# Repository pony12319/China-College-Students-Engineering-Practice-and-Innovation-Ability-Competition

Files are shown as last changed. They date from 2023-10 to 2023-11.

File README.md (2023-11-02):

# China-College-Students-Engineering-Practice-and-Innovation-Ability-Competition
2023年工训赛垃圾分类赛道代码汇总（传送带方案）
使用传送带方案，当投入多个垃圾时，第二个传送带速度更快，装有激光对射开关，可以把多个垃圾分离成一个垃圾倒入云台中
《初赛》、《决赛&国赛选拔赛》包含的是电控代码

大文件无法上传，已经整理好放百度网盘：
链接：https://pan.baidu.com/s/1K9raEiHcVAuprJ7IywbOOw?pwd=yjwt 
提取码：yjwt（包含文件：机械设计代码、两个数据集、改过的yolov5、2022年老代码）

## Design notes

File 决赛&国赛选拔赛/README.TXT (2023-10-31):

实验器材:
	正点原子精英STM32F103开发板
说明：
	1、决赛时不再满载检测，创新环节也不需要加入称重功能
	2、启用激光后对射开关速度会很慢
	3、使用光电开关跳过动画，一定要把握好时间，不然js无法正常工作（建议自己看看会出现什么结果，这次选拔赛就寄在这里...）
	4、标*是需要接线的
	
使用的引脚:
	1、VL53L0X：
		SDA--------------->PF1*
		SCL--------------->PF0*
		XSHUT1（有害）  ------------->PF2*
		XSHUT2（可回收）   ------------->PF3*
		XSHUT3（厨余）   ------------->PF4*
		XSHUT4（其他）   ------------->PF5*
		
	2、LED:
		LED0-------------->PB5
		LED1-------------->PE5
	3、KEY：
		KEY0-------------->PE4
		KEY1-------------->PE3
		WK_UP------------->PA0
	4、TPAD：
		TPAD--------------->PA0 TIM5CH2
	5、LCD:
		PB0
		PD0 PD1 PD4 PD5 PD8 PD9 PD10 PD14 PD15
		PE7 PE8 PE9 PE10 PE11 PE12 PE13 PE14 PE15
		PG0 PG12
	6、SPI：
		PB13 PB14 PB15
	7、W25QXX：
		PB12
	8、SDIO_SDCARD:
		PC8 PC9 PC10 PC11 PC12
		PD2 PD7
	9、控制倾倒的舵机：
		竖直舵机----------->PB6 TIM4CH1*
		水平舵机----------->PB9 TIM4CH4*
	10、压缩机构（24v）
		CW---------------->PF14*
		CCW--------------->PF15*
	11、控制开合的舵机：
		PB1 TIM3CH4*
	12、传送带电机：
		PWM1--------------->PA2 TIM5CH3*
		DIR1--------------->PG3*
		PWM2--------------->PA3 TIM5CH4*
		DIR1--------------->PG4*
	13、光电开关：
		SGN---------------->PF7*
	14、称重模块:
		SCK----------------->PG5*
		DOUT---------------->PG6*
	15、激光对射：
		SGN----------------->PG9*
	16、电机驱动器：
		电机1---------------->PA6 TIM3CH1*
		电机2---------------->PA7 TIM3CH2*

注意事项:
	1、js发送数据必须带上回车换行符
	2、A-------->有害垃圾
	   B-------->可回收垃圾
	   C-------->厨余垃圾
	   D-------->其他垃圾

-------------------------------------------------------------------------------------------

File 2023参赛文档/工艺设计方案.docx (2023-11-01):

四川省大学生工程训练综合能力竞赛 | 工艺设计方案 The Process Plan | | 编 号

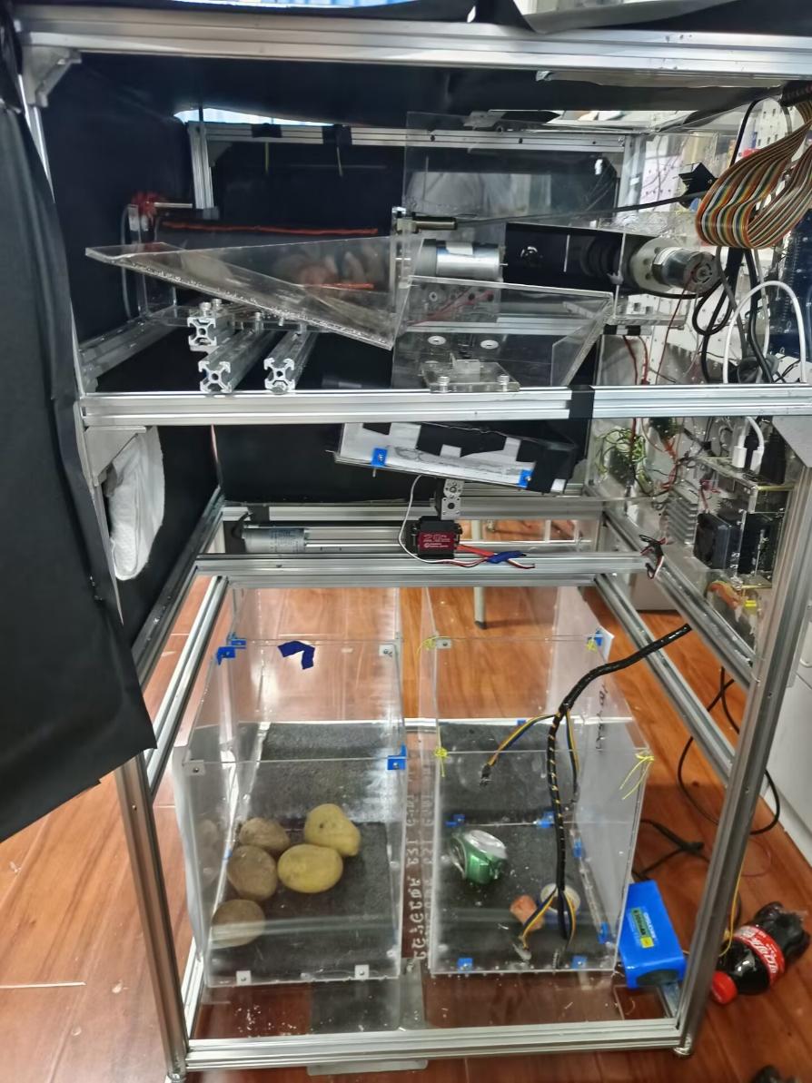
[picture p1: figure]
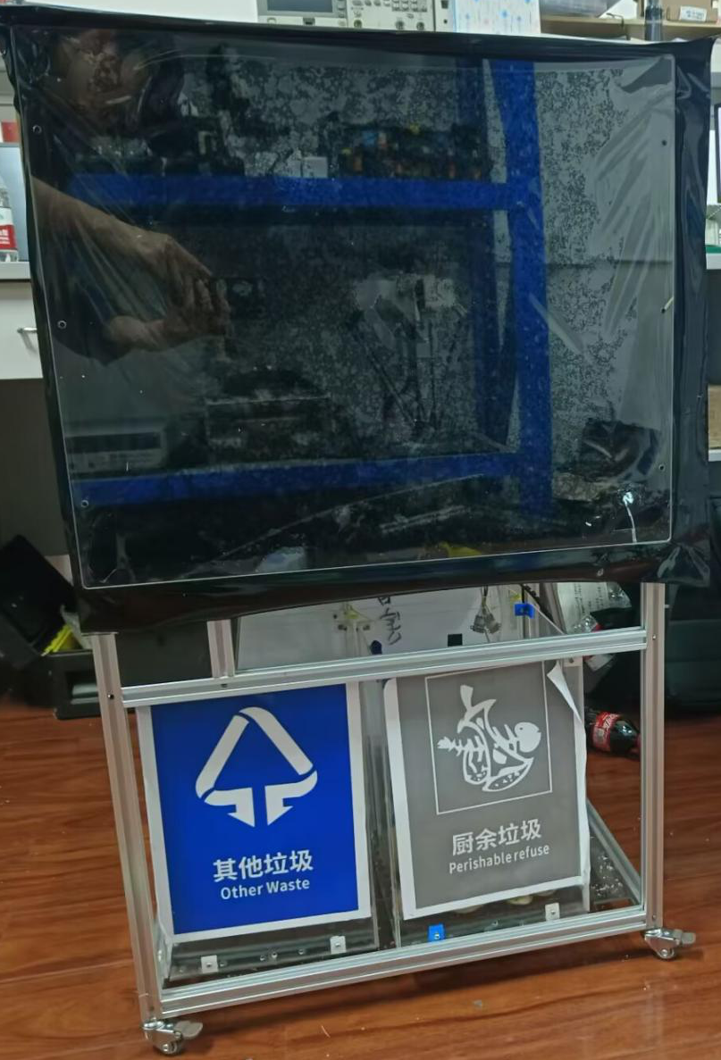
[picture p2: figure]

第一幅照片（作品正面） （注意照片的放置方向与页面方向一致， 照片上不允许出现参赛学校信息，阅后删除。） | | 第二幅照片（作品侧面） （注意照片的放置方向与页面方向一致， 照片上不允许出现参赛学校信息，阅后删除。）

学校名称：西南石油大学 参赛项目：生活垃圾智能分类

装

订

线

四川省大学生工程训练综合能力竞赛 | | | | | | | 机械加工工艺过程卡片 Machining Process Card | | | | | | 共 页 | | 第2页 | 编 号
| | | | | | | | | | | | | 产品名称 | | 垃圾桶 | 生产纲领 | 5000件/年
| | | | | | | | | | | | | 零件名称 | | 亚克力一体件 | 生产批量 | 420件/月
材料 | 亚克力 | 毛坯种类 | 亚克力料板 | | 毛坯外形尺寸 | | | 1200*900 | | 每毛坯可制作件数 | | 1 | 每台件数 | | | 备注
序 号 | 工序 名称 | 工序内容 | | | | | | | 工 序 简 图 | | | | 机床 夹具 | | 刀具 | 量具 辅具 | 工时 （min）
1 | 切割 | 激光切割 | | | | | | | 下料-对刀-切割-取件 | | | | 低压吸盘 | | CO2激光 | 刀补0.2mm | 2min
2 | 切割 | 激光切割 | | | | | | | 下料-对刀-切割-取件 | | | | 低压吸盘 | | CO2激光 | 刀补0.2mm | 4min
3 | 切割 | 激光切割 | | | | | | | 下料-对刀-切割-取件 | | | | 低压吸盘 | | CO2激光 | 刀补0.2mm | 30s
4 | 切割 | 激光切割 | | | | | | | 下料-对刀-切割-取件 | | | | 低压吸盘 | | CO2激光 | 刀补0.2mm | 5min
5 | 切割 | 亚克力热弯 | | | | | | | 放置-加热-弯折-冷却-退火 | | | | T型螺栓 | | 电热丝 | 角度尺 | 2min
6 | 切割 | 亚克力热弯 | | | | | | | 放置-加热-弯折-冷却-退火 | | | | T型螺栓 | | 电热丝 | 角度尺 | 4min
7 | 切割 | 亚克力热弯 | | | | | | | 放置-加热-弯折-冷却-退火 | | | | T型螺栓 | | 电热丝 | 角度尺 | 3min
| | | | | | | | | | | | | | | 编制（日期） | 审核（日期） | 标准化（日期）
标记 | 处数 | 更改文件号 | | 签字 | | 日期 | | | | | | | | | | 会签（日期）

学校名称：西南石油大学 参赛项目：生活垃圾智能分类

装

订

线

四川省大学生工程训练综合能力竞赛 | 加工工艺分析 Processing Technology Analysis | 共 页 | 第3页 | 编 号
| | 产品名称 | 垃圾桶 | 生产纲领 | 5000件/年
| | 零件名称 | | 生产批量 | 420件/月

1. 切割：这是亚克力一体件制作的初始步骤，也是最重要的一步。首先，需要根据设计图纸和产品要求，选择合适的亚克力板材。然后，使用专业的亚克力切割机进行切割。这个过程中，切割速度、深度和精度的控制都非常重要。如果切割过快或过深，可能会导致亚克力板材破裂；如果切割不平整，可能会影响后续的热弯和组装。

2. 热弯：热弯是将切割好的亚克力板材通过加热使其软化，然后通过压力使其弯曲成所需形状的过程。这个过程需要使用专业的热弯机，通过电热丝或者火焰加热亚克力板材，然后通过模具进行弯曲。热弯过程中，加热温度和时间的控制非常关键。如果温度过高或时间过长，可能会导致亚克力板材过热熔化；如果温度过低或时间过短，可能会导致亚克力板材弯曲不足。同时，弯曲力度和速度的控制也非常重要。如果力度过大或速度过快，可能会导致亚克力板材破裂；如果力度过小或速度过慢，可能会导致亚克力板材弯曲过度。

3. 后处理：热弯完成后，亚克力一体件还需要经过打磨、抛光等后处理工序，以提高其表面光洁度和美观度。这个过程需要使用专业的打磨机和抛光机，通过不同的砂纸和抛光膏进行打磨和抛光。后处理过程中，需要注意控制打磨和抛光的力度和速度，以防止亚克力板材破损或者表面划伤。

4. 表面处理：最后，根据需要可能还需要进行喷漆、丝印等表面处理，以增加产品的耐用性和美观性。这个过程需要使用专业的喷漆机和丝印机，通过选择不同的颜色和图案进行喷漆和丝印。表面处理过程中，需要注意控制喷漆和丝印的厚度和均匀度，以防止产品表面不平整或者颜色不均匀。

学校名称：西南石油大学 参赛项目：生活垃圾智能分类

装

订

线

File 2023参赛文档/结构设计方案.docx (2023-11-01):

四川省大学生工程训练综合能力竞赛项目
结构设计方案 | | | | 编 号

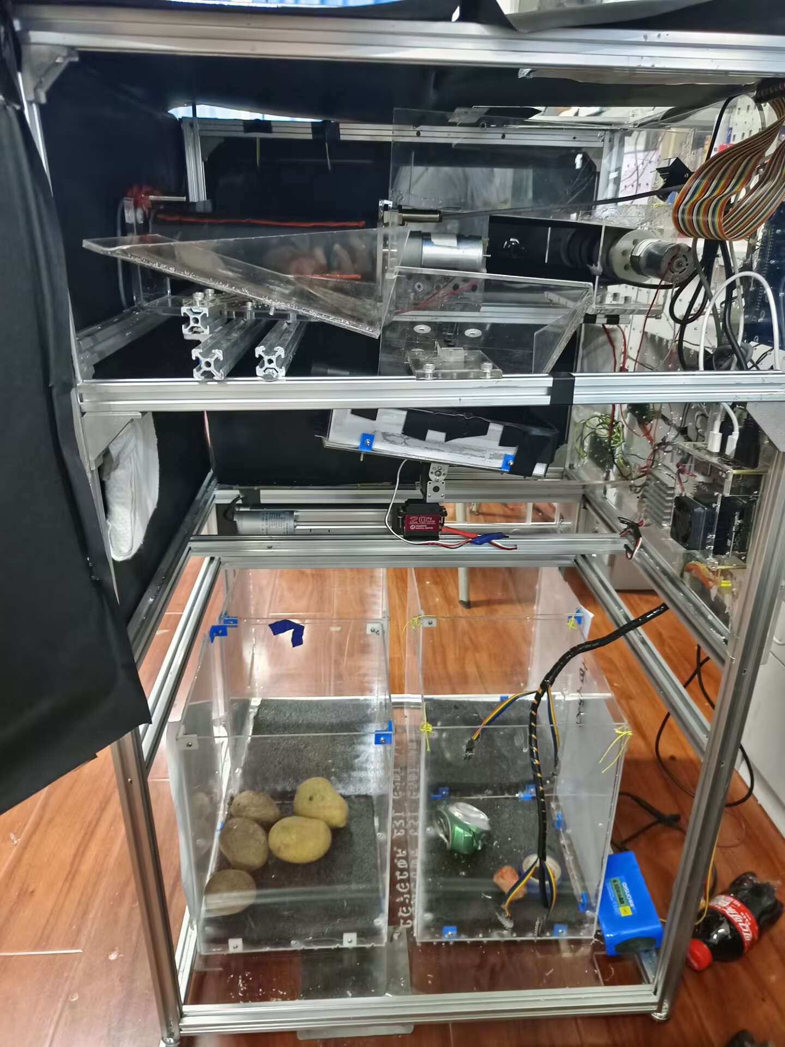
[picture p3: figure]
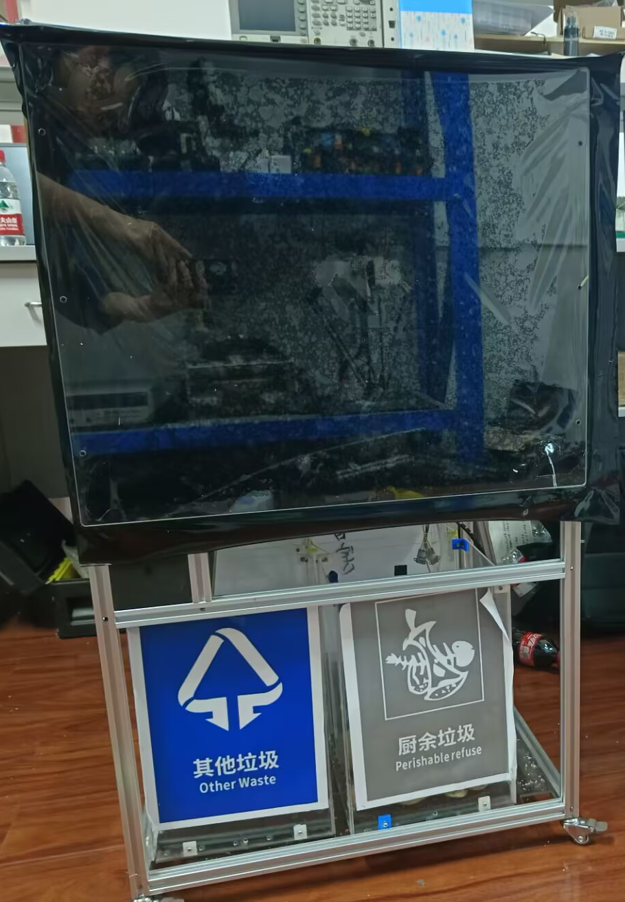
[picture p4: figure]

产品名称 | 垃圾桶 | 共 5 页 | 第 1 页 | | 编 号

学校名称：西南石油大学 队号 ：Z2-29 参赛项目：生活垃圾智能分类

装

订

线

四川省大学生工程训练综合能力竞赛项目
结构设计方案 Structure Design Scheme | | | | 参赛项目
| | | | 生活垃圾智能分类

1、设计思路

外壳采用3mm亚克力与黑磨砂纸的组合以提供利于视觉识别的环境；框架采用铝型材及圆头螺丝装配来保证整体框架的稳定性及应有的韧性、刚性等等；线路板部分采用5mm亚克力切割安装，保证了良好的可加工性与安装稳定性；内部异性结构件采用复合材料3D打印，使得材料的强度有保障；对于部分非标承重件采用了金属烧结，以获得优异的结构性能。

2、总体结构方案

先准备好各项材料，用铝型材组装出整体框架，安装底板，安装脚轮，安装云台，安装压缩装置，安装开合装置，安装线路板，安装传送带，安装滑道，安装四周板，安装顶板。

3、总结和体会

1、再一次考验并验证了我的制造加工装配能力；

2、为结构工业化提出并实践了部分参考；

3、对身体素质进行了一些简单的测试；

4、再次验证了我的个人效率及积极性。
产品名称 | 垃圾桶 | 共 5 页 | 第 2 页 | | 编 号

学校名称：西南石油大学 队号 ：Z2-29 参赛项目：生活垃圾智能分类

装

订

线

四川省大学生工程训练综合能力竞赛项目
结构设计方案 Structure Design Scheme | | | | 参赛项目
| | | | 生活垃圾智能分类

4、 结构设计创新特色说明

1、对部分结构件采用了一体化成型；

2、采用了工业级的激光对射开关并修改至能被单片机使用；

3、对铝型材采用了空间利用率更高的连接方式；

4、充分使用铝型材专用配件使得垃圾箱整体更符合日常使用习惯并获得更大的灵活性。
产品名称 | 垃圾桶 | 共 5 页 | 第 3 页 | | 编 号

学校名称：西南石油大学 队号 ：Z2-29 参赛项目：生活垃圾智能分类

装

订

线

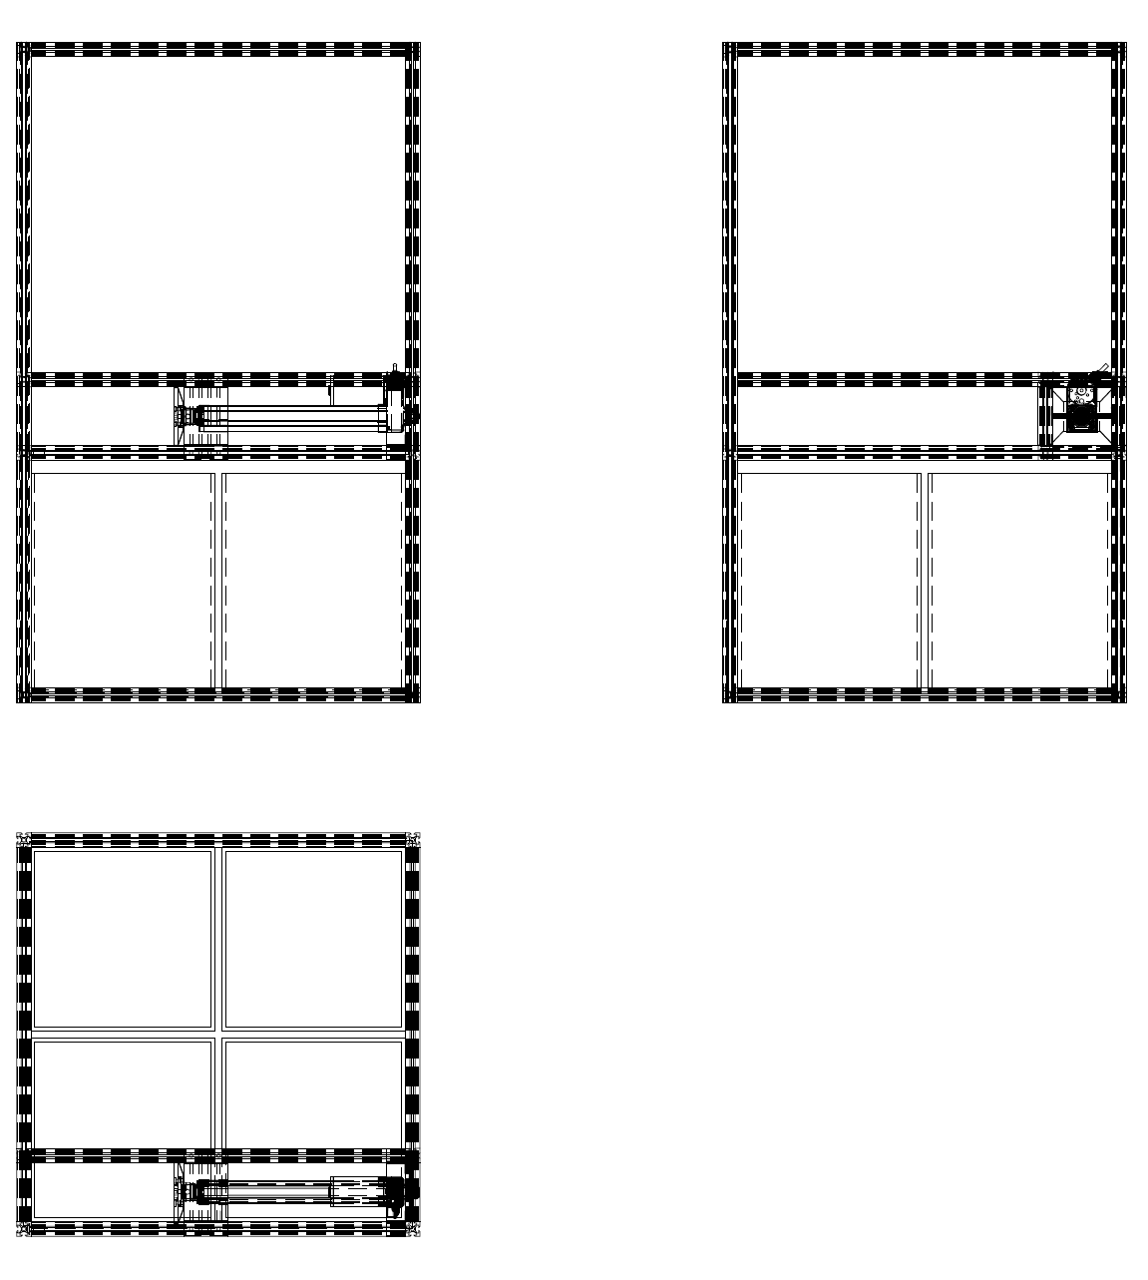
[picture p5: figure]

| 装配图 | 比例 | 第 4 页
| 四川省大学生工程训练综合能力竞赛项目 | 1：20 | 共 5 页

装

订

线

学校名称：西南石油大学 队号 ：Z2-29 参赛项目：生活垃圾智能分类

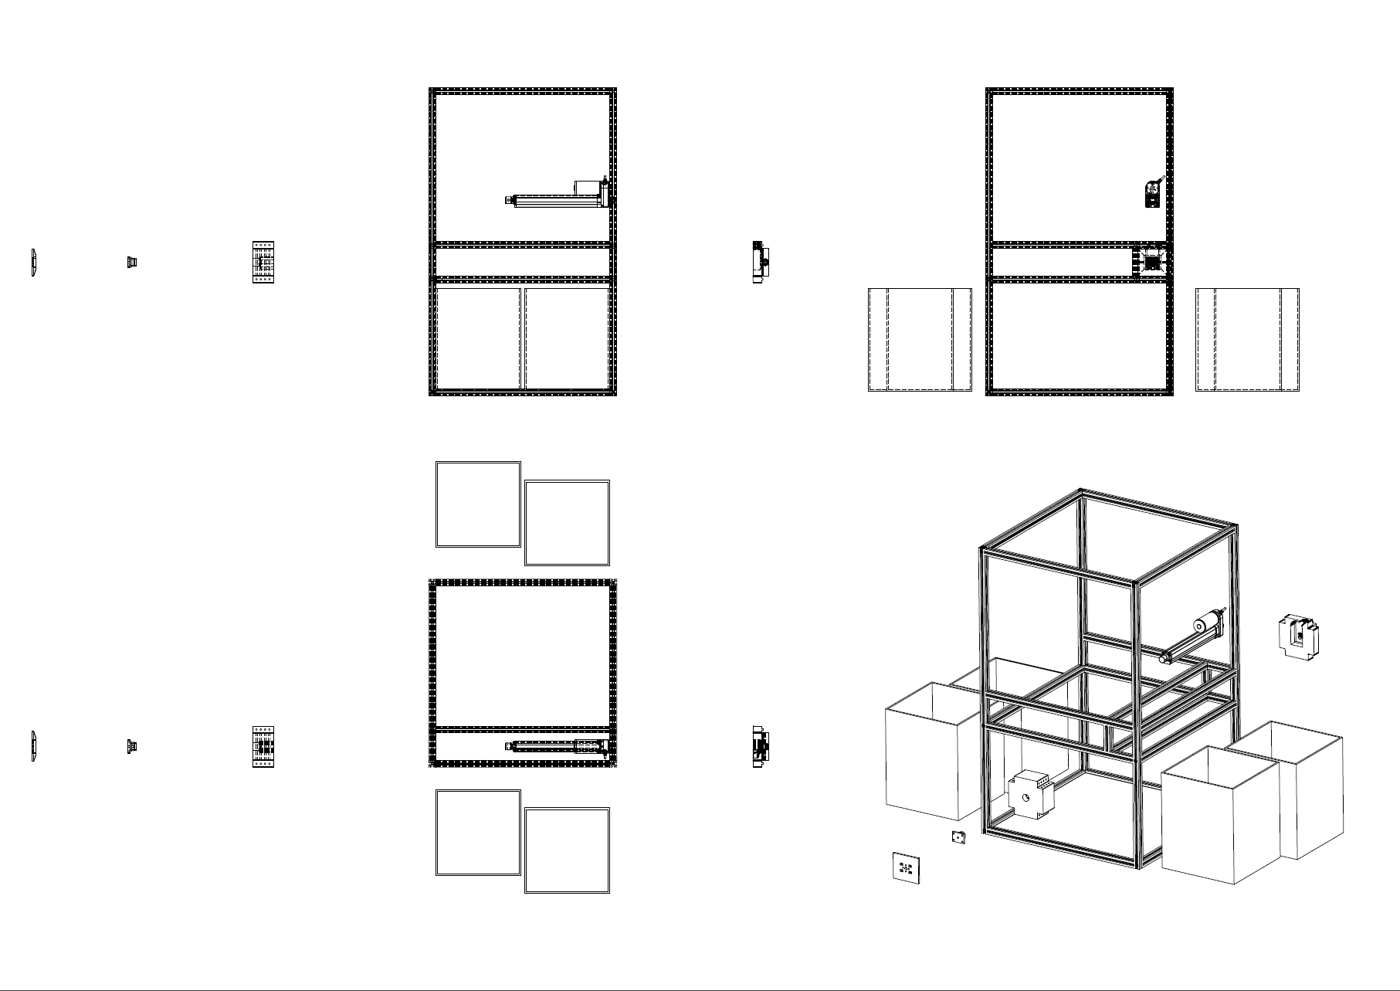
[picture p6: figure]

| 爆炸图 | 比 例 | 第 5 页
| 四川省大学生工程训练综合能力竞赛项目 | 1：20 | 共 5 页

学校名称：西南石油大学 队号 ：Z2-29 参赛项目：生活垃圾智能分类

装

订

线

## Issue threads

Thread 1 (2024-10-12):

视觉

maomao725, 2024-10-12:
大佬你的视觉代码在哪呀...我看了挺多文件，感觉全是电控方面的

maomao725, 2024-10-12:
就是视觉到什么类型垃圾然后和单片机串口通信的的代码

pony12319, 2024-10-16:
视觉代码在百度网盘链接中，和数据集一起打包好的

maomao725, 2025-02-07:
谢谢大佬！！！如果我想用solidworks画一个传送带垃圾桶 今年规则也缩小了尺寸 我想问问应该从什么地方画起 有什么思路吗...现在一画我就觉得抽象

pony12319, 2025-02-14:
机械不是我搞的，不是很明白。项目里面好像附上了机械的联系方式，请联系他谢谢

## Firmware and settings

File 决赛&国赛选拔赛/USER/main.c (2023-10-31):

#include "sys.h"
#include "delay.h"
#include "usart.h" 
#include "led.h" 		 	 
#include "lcd.h"  
#include "key.h"     
#include "malloc.h"
#include "sdio_sdcard.h"  
#include "w25qxx.h"    
#include "ff.h"  
#include "exfuns.h"   
#include "text.h"
#include "piclib.h"	
#include "string.h"		
#include "math.h"
#include "vl53l0x.h"
#include "vl53l0x_gen.h"
#include "tpad.h"
#include <stdarg.h>
#include "stdio.h"
#include "servo.h"
#include "compressor.h"
#include "belt.h"
#include "InfrarePSwitch.h"
#include "timer.h"

//得到path路径下,目标文件的总个数
//path:路径		    
//返回值:总有效文件数
u16 pic_get_tnum(u8 *path)
{	  
	u8 res;
	u16 rval=0;
 	DIR tdir;	 		//临时目录
	FILINFO tfileinfo;	//临时文件信息	
	u8 *fn;	 			 			   			     
    res=f_opendir(&tdir,(const TCHAR*)path); 	//打开目录
  	tfileinfo.lfsize=_MAX_LFN*2+1;				//长文件名最大长度
	tfileinfo.lfname=mymalloc(SRAMIN,tfileinfo.lfsize);//为长文件缓存区分配内存
	if(res==FR_OK&&tfileinfo.lfname!=NULL)
	{
		while(1)//查询总的有效文件数
		{
	        res=f_readdir(&tdir,&tfileinfo);       		//读取目录下的一个文件
	        if(res!=FR_OK||tfileinfo.fname[0]==0)break;	//错误了/到末尾了,退出		  
     		fn=(u8*)(*tfileinfo.lfname?tfileinfo.lfname:tfileinfo.fname);			 
			res=f_typetell(fn);	
			if((res&0XF0)==0X50)//取高四位,看看是不是图片文件	
			{
				rval++;//有效文件数增加1
			}	    
		}  
	} 
	return rval;
}

//播放gif视频
//注意：只支持gif格式播放，其他格式未测试
void show_video()
{
	u8 res;
 	DIR picdir;	 		//图片目录
	FILINFO picfileinfo;//文件信息
	u8 *fn;   			//长文件名
	u8 *pname;			//带路径的文件名
	u16 totpicnum; 		//图片文件总数
	u16 curindex;		//图片当前索引
	u8 key;				//键值
	u8 pause=0;			//暂停标记
	u8 t;
	u16 temp;
	u16 *picindextbl;	//图片索引表
	
	while(f_opendir(&picdir,"0:/PICTURE"))//打开图片文件夹
 	{	    
		Show_Str(30,170,240,16,"PICTURE文件夹错误!",16,0);
		delay_ms(200);				  
		LCD_Fill(30,170,240,186,WHITE);//清除显示	     
		delay_ms(200);				  
	}  
	totpicnum=pic_get_tnum("0:/PICTURE"); //得到总有效文件数
  	while(totpicnum==NULL)//图片文件为0		
 	{	    
		Show_Str(30,170,240,16,"没有图片文件!",16,0);
		delay_ms(200);				  
		LCD_Fill(30,170,240,186,WHITE);//清除显示	     
		delay_ms(200);				  
	}
  	picfileinfo.lfsize=_MAX_LFN*2+1;						//长文件名最大长度
	picfileinfo.lfname=mymalloc(SRAMIN,picfileinfo.lfsize);	//为长文件缓存区分配内存
 	pname=mymalloc(SRAMIN,picfileinfo.lfsize);				//为带路径的文件名分配内存
 	picindextbl=mymalloc(SRAMIN,2*totpicnum);				//申请2*totpicnum个字节的内存,用于存放图片索引
 	while(picfileinfo.lfname==NULL||pname==NULL||picindextbl==NULL)//内存分配出错
 	{	    
		Show_Str(30,170,240,16,"内存分配失败!",16,0);
		delay_ms(200);				  
		LCD_Fill(30,170,240,186,WHITE);//清除显示	     
		delay_ms(200);				  
	}  	
	//记录索引
    res=f_opendir(&picdir,"0:/PICTURE"); //打开目录
	if(res==FR_OK)
	{
		curindex=0;//当前索引为0
		while(1)//全部查询一遍
		{
			temp=picdir.index;								//记录当前index
	        res=f_readdir(&picdir,&picfileinfo);       		//读取目录下的一个文件
	        if(res!=FR_OK||picfileinfo.fname[0]==0)break;	//错误了/到末尾了,退出		  
     		fn=(u8*)(*picfileinfo.lfname?picfileinfo.lfname:picfileinfo.fname);			 
			res=f_typetell(fn);	
			if((res&0XF0)==0X50)//取高四位,看看是不是图片文件	
			{
				picindextbl[curindex]=temp;//记录索引
				curindex++;
			}	    
		} 
	}   
	//Show_Str(30,170,240,16,"开始显示...",16,0); 
	delay_ms(1500);
	piclib_init();										//初始化画图	   	   
	curindex=0;											//从0开始显示
   	res=f_opendir(&picdir,(const TCHAR*)"0:/PICTURE"); 	//打开目录
	while(res==FR_OK)//打开成功
	{	
		//printf("open ok\r\n");
		
		dir_sdi(&picdir,picindextbl[curindex]);			//改变当前目录索引	   
        res=f_readdir(&picdir,&picfileinfo);       		//读取目录下的一个文件
        if(res!=FR_OK||picfileinfo.fname[0]==0)break;	//错误了/到末尾了,退出
     	fn=(u8*)(*picfileinfo.lfname?picfileinfo.lfname:picfileinfo.fname);			 
		strcpy((char*)pname,"0:/PICTURE/");				//复制路径(目录)
		strcat((char*)pname,(const char*)fn);  			//将文件名接在后面
 		LCD_Clear(BLACK);
		//printf("start show \r\rn");
 		res = ai_load_picfile(pname,0,0,lcddev.width,lcddev.height,1);//显示图片  
		//printf("res=%d\r\n", res);
		//printf("stop show\r\n");
//		Show_Str(2,2,240,16,pname,16,1); 				//显示图片名字
		t=0;
		while(1) 
		{
			//printf("index:%d\r\n", curindex);

			curindex++;		   	
			if(curindex>=totpicnum)curindex=0;//到末尾的时候,自动从头开始
			break;

		}					    
		//res=0;  
	} 											  
	myfree(SRAMIN,picfileinfo.lfname);	//释放内存			    
	myfree(SRAMIN,pname);				//释放内存			    
	myfree(SRAMIN,picindextbl);			//释放内存	

	
}
// 格式化并显示字符串
void DisplayFormattedString(int x, int y, int width, int height, const char *format, ...) 
{
    char buffer[256]; // 用于存储格式化后的字符串
    va_list args;
    va_start(args, format);
    vsnprintf(buffer, sizeof(buffer), format, args);
    va_end(args);

    Show_Str(x, y, width, height, buffer, 24, 0);
}


 int main(void)
 {	 
	 u8 order = 1, flag = 0;//垃圾顺序 是否有垃圾遮挡对射开关
	 u16 position = 30;//y坐标
	 u16 len;
	 char t;//暂存串口值
	 int i = 1490, j = 1655, k=1490;//i水平控制参数，j倾斜控制参数
	 
	 // 定义一个二维字符数组来存储垃圾名称
    const char garbages[4][20] = {
        "有害垃圾",
		"可回收垃圾", 
		"厨余垃圾",
		"其他垃圾"
    };
	TIM6_Init();//计时器初始化
	delay_init();	    	 //延时函数初始化	  
    NVIC_PriorityGroupConfig(NVIC_PriorityGroup_2);//设置中断优先级分组为组2：2位抢占优先级，2位响应优先级
	uart_init(9600);	 	//串口初始化为9600
	belt_init();
	start_belt();
	My_TIM4_Init(20000-1,72-1);//周期为20ms
	Compressor_Init();
	Switch_Init();//光电开关初始化
	TIM_SetCompare4(TIM4,1750);     //接1  初始105度
	delay_ms(1000);
	TIM_SetCompare1(TIM4,1490);     //接0水平舵机 初始90度
	Servo_SetAngle(90); //开合舵机初始化 90度				
	start_belt();
	LCD_Init();			   		//初始化LCD   
	W25QXX_Init();				//初始化W25Q128
 	my_mem_init(SRAMIN);		//初始化内部内存池
	exfuns_init();				//为fatfs相关变量申请内存  
 	f_mount(fs[0],"0:",1); 		//挂载SD卡 
 	f_mount(fs[1],"1:",1); 		//挂载FLASH.
    POINT_COLOR=RED;      
	while(font_init()) 		//检查字库
	{	    
		LCD_ShowString(30,50,200,16,16,"Font Error!");
		delay_ms(200);				  
		LCD_Fill(30,50,240,66,WHITE);//清除显示	     
		delay_ms(200);				  
	}  
		
	Show_Str(30, 50, 200, 24, "垃圾分类实验", 24, 0);
	delay_ms(1000);
	
	show_video();
//	while(1)
//	{
//		printf("ok");
//		if(USART_RX_STA&0x8000)
//		{
//			len = USART_RX_STA&0x3fff;
//			if(USART_RX_BUF[0] == 's')
//			{
//				USART_RX_STA=0;
//				break;
//			}
//				
//		}
//		delay_ms(300);
//		
//	}
	//开始检测
	printf("ok");

 	
	LCD_Fill(0,0,800,480,WHITE);//清除显示
	Show_Str(0,0,500,30,"序号  垃圾种类    数量  状态",24,0);
	maxtime = 0;
	TIM_Cmd(TIM6,DISABLE);
	delay_ms(10);
	TIM_Cmd(TIM6,ENABLE);

	
	while(1)
		{
			//当对射开关被垃圾遮挡，传送带在0.3s后停止，等待处理
			if (IsAnything())
			{
				delay_ms(300);
				stop_belt();
				flag = 1;
			}
				
			
			if (USART_RX_STA&0x8000)
			{
				len = USART_RX_STA&0x3fff;
				t = USART_RX_BUF[0]; 
				switch(t)
				{
					//有害垃圾
					case 'A':
						stop_belt();
						
						//水平旋转
						while(i <= 2480)
						{
							TIM_SetCompare1(TIM4,i);
							delay_ms(10);
							i += 11;
						}
						delay_ms(300);
						
						//倾倒动作
						while(j >= 1350)
						{
							TIM_SetCompare4(TIM4,j);
							delay_ms(25);
							j -= 11;
						}
						delay_ms(1000);                  //等待垃圾倒下
						
						//回正
						while(j <= 1780)
						{
								TIM_SetCompare4(TIM4,j);
								delay_ms(1);
								j += 11;
						}
						if(i <= 1490)
						{
								while(i <= 1490)
								{
									 TIM_SetCompare1(TIM4,i);
									 delay_ms(1);
									 i += 11;
								}
						}
						else if(i > 1501)
						{
								while(i >= 1490)
								{
									 TIM_SetCompare1(TIM4,i);
									 delay_ms(1);
									 i -= 11;
								}
						}
						
						//显示信息
						DisplayFormattedString(0, position, 550, 30, "%d    %s     1      ok!", order, garbages[0]);
						order += 1;
						position += 30;
						if (position>=450)
							position = 30;
						USART_RX_STA=0;
						start_belt();
						printf("cc");
						maxtime = 0;
						flag = 0;
						uart_init(9600);
						break;
					
						//可回收垃圾
					case 'B':
						stop_belt();
					
						//水平选择
						while(i >= 500)
						{
							TIM_SetCompare1(TIM4,i);
							delay_ms(10);
							i -= 11;
						}
						delay_ms(300);
					
						//倾倒动作
						while(j >= 1480)
						{
							TIM_SetCompare4(TIM4,j);
							delay_ms(25);
							j -= 11;
						}
						delay_ms(1000);                  //等待垃圾倒下
						Compressor_Press();		//压缩垃圾	
						uart_init(9600);
						Dump();				
						
						//控制开合
						while(k<1700)
						{
							TIM_SetCompare4(TIM3,i);
							delay_ms(5);
							k+=50;
						}
						while(k>1500)
						{
							TIM_SetCompare4(TIM3,i);
							delay_ms(5);
							k-=50;
						}
						
						
								
						//回正
						while(j <= 1780)
						{
								TIM_SetCompare4(TIM4,j);
								delay_ms(1);
								j += 11;
						}
						if(i <= 1490)
						{
								while(i <= 1490)
								{
									 TIM_SetCompare1(TIM4,i);
									delay_ms(1);
									 i += 11;
								}
						}
						else if(i > 1501)
						{
								while(i >= 1490)
								{
									 TIM_SetCompare1(TIM4,i);
									 delay_ms(1);
									 i -= 11;
								}
						}
						
						//显示信息
						DisplayFormattedString(0, position, 550, 30, "%d    %s   1      ok!", order, garbages[1]);
						order += 1;
						position += 30;
						if (position>=450)
							position = 30;
						USART_RX_STA=0;
						start_belt();
						printf("cc");
						maxtime = 0;
						flag = 0;
						break;

						//厨余垃圾
					case 'C':
						stop_belt();
											//水平转动
						while(i <= 1820)
						{
							TIM_SetCompare1(TIM4,i);
							delay_ms(10);
							i += 11;
						}
						delay_ms(6);
						
						//倾倒动作
						while(j >= 1350)
						{
							TIM_SetCompare4(TIM4,j);
							delay_ms(25);
							j -= 11;
						}
						delay_ms(1000);                  //等待垃圾倒下
						
						
						//回正
						while(j <= 1780)
						{
								TIM_SetCompare4(TIM4,j);
								delay_ms(1);
								j += 11;
						}
						if(i <= 1490)
						{
								while(i <= 1490)
								{
									 TIM_SetCompare1(TIM4,i);
									 delay_ms(1);
									 i += 11;
								}
						}
						else if(i > 1501)
						{
								while(i >= 1490)
								{
									 TIM_SetCompare1(TIM4,i);
									 delay_ms(1);
									 i -= 11;
								}
						}
						
						//显示信息
						DisplayFormattedString(0, position, 550, 30, "%d    %s     1      ok!", order, garbages[2]);
						order += 1;
						position += 30;
						if (position>=450)
							position = 30;
						USART_RX_STA=0;
						start_belt();
						printf("cc");
						maxtime = 0;
						flag = 0;
						uart_init(9600);
						break;
						
						//其他垃圾
					case 'D':
						stop_belt();
					
						while(i >= 1160)
						{
							TIM_SetCompare1(TIM4,i);
							delay_ms(10);
							i -= 11;
						}
						delay_ms(300);
						
						//倾倒动作
						while(j >= 1370)
						{
							TIM_SetCompare4(TIM4,j);
							delay_ms(30);
							j -= 11;
						}
						delay_ms(1000);                  //等待垃圾倒下
						delay_ms(1000); 
						
						//回正
						while(j <= 1780)
						{
								TIM_SetCompare4(TIM4,j);
								delay_ms(1);
								j += 11;
						}
						if(i <= 1490)
						{
								while(i <= 1490)
								{
									 TIM_SetCompare1(TIM4,i);
									 delay_ms(1);
									 i += 11;
								}
						}
						else if(i > 1501)
						{
								while(i >= 1490)
								{
									 TIM_SetCompare1(TIM4,i);
									 delay_ms(1);
									 i -= 11;
								}
						}
						
						//显示信息
						DisplayFormattedString(0, position, 550, 30, "%d    %s     1      ok!", order, garbages[3]);
						order += 1;
						position += 30;
						if (position>=450)
							position = 30;
						USART_RX_STA=0;
						start_belt();
						printf("cc");
						maxtime = 0;
						flag = 0;
						uart_init(9600);
						break;
						
				}
				
			}
			
			//10个垃圾后不再判断超时
			if (order == 10)
			{
				TIM_Cmd(TIM6,DISABLE);
				maxtime = 0;
			}
			
			//识别不了都按其他垃圾处理
			if (flag == 1)
			{
				if (maxtime >= 7)
				{
					while(i >= 1160)
						{
							TIM_SetCompare1(TIM4,i);
							delay_ms(10);
							i -= 11;
						}
						delay_ms(300);
						
						//倾倒动作
						while(j >= 1370)
						{
							TIM_SetCompare4(TIM4,j);
							delay_ms(30);
							j -= 11;
						}
						delay_ms(1000);                  //等待垃圾倒下
						delay_ms(1000); 
						
						//回正
						while(j <= 1780)
						{
								TIM_SetCompare4(TIM4,j);
								delay_ms(1);
								j += 11;
						}
						if(i <= 1490)
						{
								while(i <= 1490)
								{
									 TIM_SetCompare1(TIM4,i);
									 delay_ms(1);
									 i += 11;
								}
						}
						else if(i > 1501)
						{
								while(i >= 1490)
								{
									 TIM_SetCompare1(TIM4,i);
									 delay_ms(1);
									 i -= 11;
								}
						}
						
						//显示信息
						DisplayFormattedString(0, position, 550, 30, "%d    %s     1      ok!", order, garbages[3]);
						order += 1;
						position += 30;
						if (position>=450)
							position = 30;
						USART_RX_STA=0;
						start_belt();
						maxtime = 0;
						flag = 0;
						uart_init(9600);
						
				}
			}
			
			
	    }
}

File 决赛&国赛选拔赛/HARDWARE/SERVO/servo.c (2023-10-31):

#include "servo.h"
#include "delay.h"

//PB6,PB9 TIM4的CH1和CH4
//PA1  的TIM2 CH2
void My_TIM4_Init(u16 arr,u16 psc)
{
    GPIO_InitTypeDef GPIO_InitStruct;
    TIM_TimeBaseInitTypeDef TIM_TimeBaseInitStruct;
    TIM_OCInitTypeDef TIM_OCInitStruct;
     
    RCC_APB2PeriphClockCmd(RCC_APB2Periph_GPIOB | RCC_APB2Periph_GPIOA,ENABLE);
    RCC_APB1PeriphClockCmd(RCC_APB1Periph_TIM4 | RCC_APB1Periph_TIM2,ENABLE);
    RCC_APB2PeriphClockCmd(RCC_APB2Periph_AFIO,ENABLE);
	
     
    GPIO_InitStruct.GPIO_Mode=GPIO_Mode_AF_PP;//复用推挽
	GPIO_InitStruct.GPIO_Pin=GPIO_Pin_6|GPIO_Pin_9|GPIO_Pin_1 | GPIO_Pin_7 |GPIO_Pin_8;
    GPIO_InitStruct.GPIO_Speed=GPIO_Speed_50MHz;
    GPIO_Init(GPIOB, &GPIO_InitStruct);
	
	GPIO_InitStruct.GPIO_Pin=GPIO_Pin_1;
	GPIO_Init(GPIOA, &GPIO_InitStruct);
	
    TIM_TimeBaseInitStruct.TIM_Period=arr;//自动重装载值
    TIM_TimeBaseInitStruct.TIM_Prescaler=psc;//预分频系数
			
    TIM_OCInitStruct.TIM_OCMode=TIM_OCMode_PWM1;
    TIM_OCInitStruct.TIM_OCNPolarity=TIM_OCPolarity_High;
    TIM_OCInitStruct.TIM_OutputState=TIM_OutputState_Enable;

    TIM_TimeBaseInit(TIM4, &TIM_TimeBaseInitStruct);
	TIM_TimeBaseInit(TIM2, &TIM_TimeBaseInitStruct);
	
//    TIM_OC3Init(TIM4,&TIM_OCInitStruct);//通道1
    TIM_OC2Init(TIM4,&TIM_OCInitStruct);//通道2
	TIM_OC1Init(TIM4,&TIM_OCInitStruct);//通道3
    TIM_OC4Init(TIM4,&TIM_OCInitStruct);//通道4
	
	TIM_OC2Init(TIM2,&TIM_OCInitStruct);//通道4
     
    TIM_OC1PreloadConfig(TIM4,TIM_OCPreload_Enable);        //使能预装载寄存器
    TIM_OC2PreloadConfig(TIM4,TIM_OCPreload_Enable);
	TIM_OC2PreloadConfig(TIM2,TIM_OCPreload_Enable);
	
    TIM_Cmd(TIM4,ENABLE);        //使能TIM4
	TIM_Cmd(TIM2,ENABLE);        //使能TIM4
         
}

void Servo_SetAngle(float Angle)
{
	TIM_SetCompare2(TIM2, Angle / 180 * 2000 + 500);
}

void Dump(void)
{
	Servo_SetAngle(0);
	delay_ms(1000);
	delay_ms(500);
	Servo_SetAngle(90);

}

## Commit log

2023-10-31 第一次提交
2023-11-01 Add files via upload
    2023年参赛文档（水得很）
2023-11-01 Update README.md
    提交了视觉代码
2023-11-02 Update README.md
    上传了机械代码
